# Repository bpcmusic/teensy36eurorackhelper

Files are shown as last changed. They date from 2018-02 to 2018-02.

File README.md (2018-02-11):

# teensy36eurorackhelper
little board to help the teensy 3.6 boot in eurorack modules

---

Mount this little fellow underneath your Teensy 3.6 if you are having trouble booting when mounted in place of a Teensy 3.2 in a Eurorack module. The symptom is that the module never executes your code when booted without USB power.

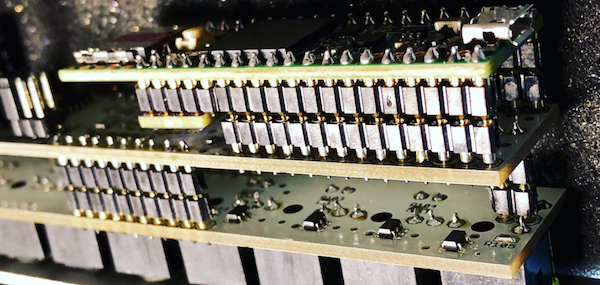
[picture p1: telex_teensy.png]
Teensy 3.6 on TXo


This board adds a voltage supervisor that delays the start of the Teensy (via the Reset pin) until there is adequate power. It was designed to fit on the bottom of the board in an area that would not be populated for a Teensy 3.2.

Top Botton



You can always use Eagle to create your own Gerbers and select your own fab house.

## Project BOM:

* 1 x MIC803 (MIC803-26D2VM3-TR
): http://www.mouser.com/search/ProductDetail.aspx?r=998%2dMIC803%2d26D2VM3TR

* 1 x 100k 1% 0603 Resistor (71-CRCW0603100KFKEAC
): https://www.mouser.com/ProductDetail/71-CRCW0603100KFKEAC?r=71-CRCW0603100KFKEAC

* 2 x 1x4 Male Headers (appropriate to your installation)

* 1 x 1x5 Male Header (appropriate to your installation)

---

More details are in this thread over at the Teensy forum: 

https://forum.pjrc.com/threads/44704-Boot-on-Power-Up-Problem-with-three-T3-6s

Thanks to everyone there (especially neutron7) for finding the solution. All I did was panel the thing up. Saved my bacon on a project. :)

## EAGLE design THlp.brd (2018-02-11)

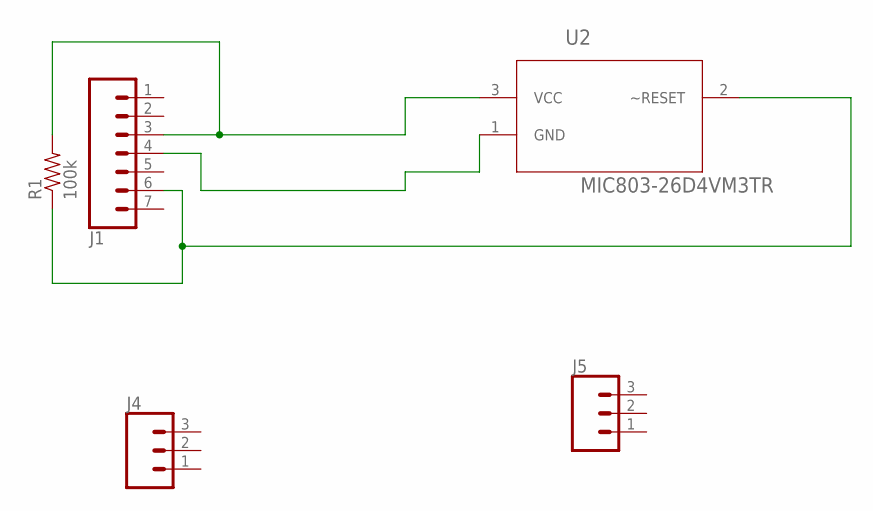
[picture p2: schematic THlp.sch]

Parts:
J1: CONN_07; 1X07
J4, J5: CONN_03PTH; 1X03
R1: 100k; 0603-RES
U2: MIC803-26D4VM3TR; SOT95P232X110-3N

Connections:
unnamed: J1.4, U2.1 (GND)
unnamed: J1.3, R1.2, U2.3 (VCC)
unnamed: J1.6, R1.1, U2.2 (~RESET)

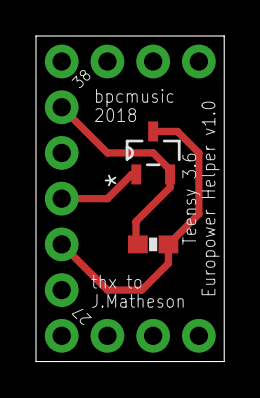
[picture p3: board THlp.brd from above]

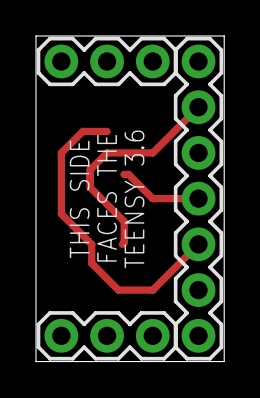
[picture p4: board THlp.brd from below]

Board: 2 copper layers, 10.5 x 18.1 mm, 5 parts (3 on the bottom side), 3 nets.

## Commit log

2018-02-11 initial commit of files
    [THlp.brd, THlp.sch]
2018-02-11 added BOM

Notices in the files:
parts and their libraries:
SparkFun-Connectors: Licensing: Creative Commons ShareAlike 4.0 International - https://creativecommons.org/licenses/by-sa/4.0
